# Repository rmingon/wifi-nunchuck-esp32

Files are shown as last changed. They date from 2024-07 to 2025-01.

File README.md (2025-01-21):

# Esp32 nunchuck

# video

Watch the video (https://youtu.be/Svnkp6KxDMc)

### Project for use a wii nunchuck on wifi or bluetooth

### 3d view
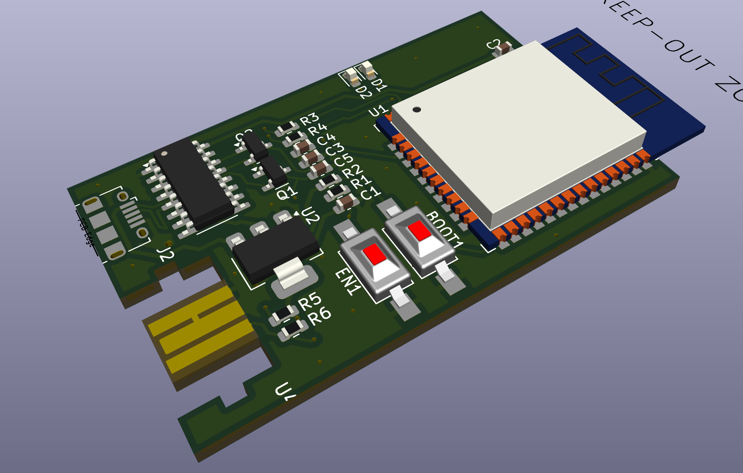
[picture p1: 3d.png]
wifi nunchuck 3d view


### Schematic view
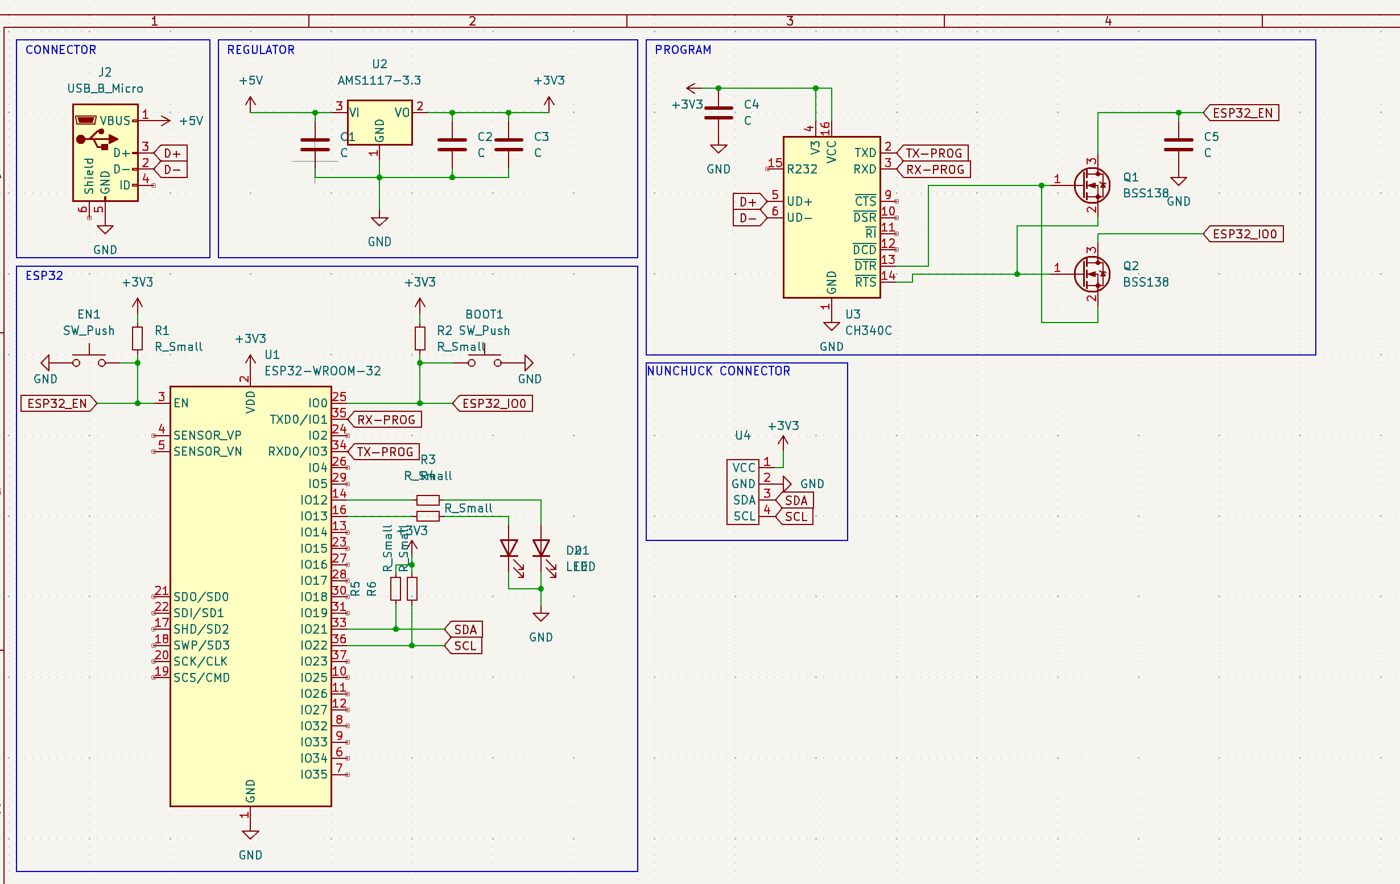
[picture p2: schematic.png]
wifi nunchuck schematic view


### Pcb view
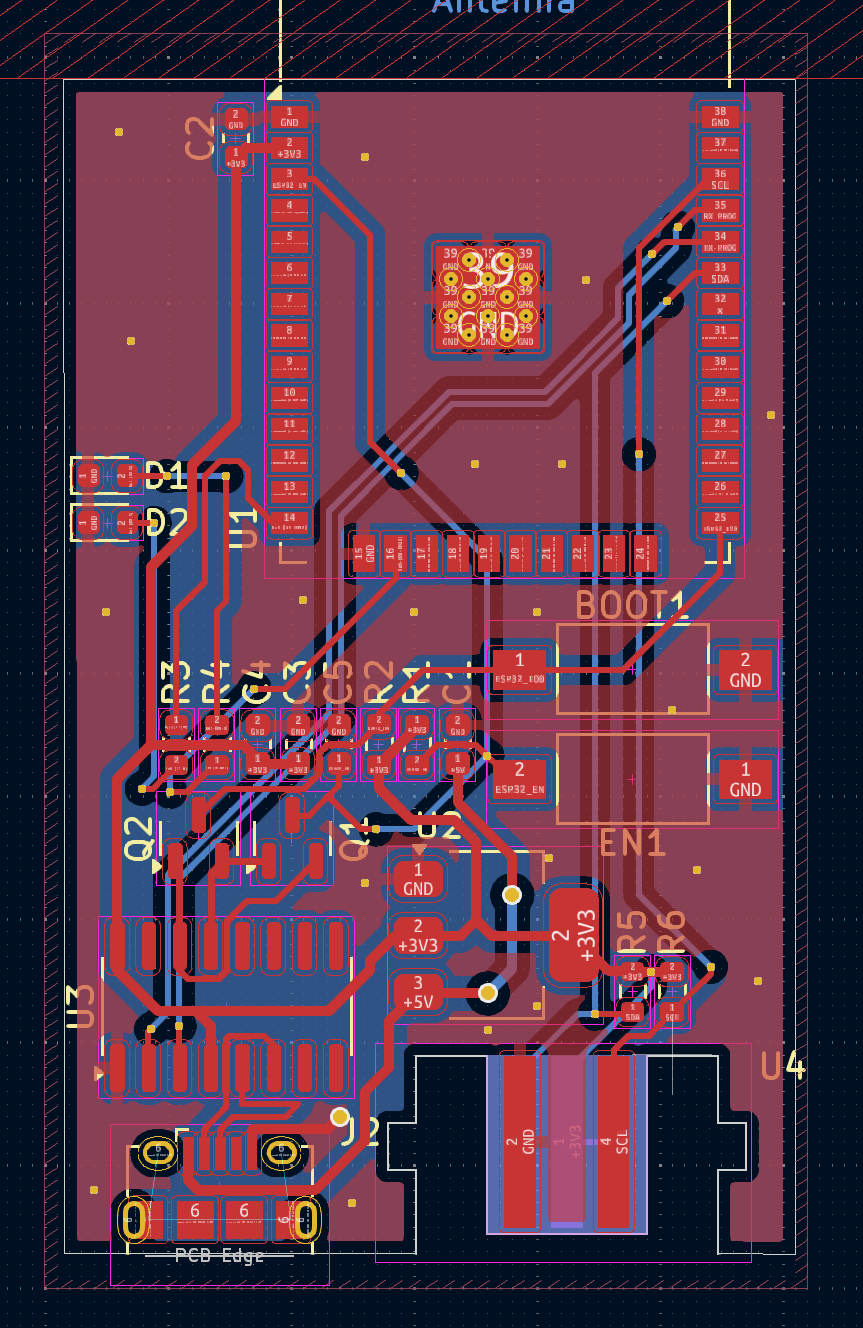
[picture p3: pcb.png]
wifi nunchuck pcb view


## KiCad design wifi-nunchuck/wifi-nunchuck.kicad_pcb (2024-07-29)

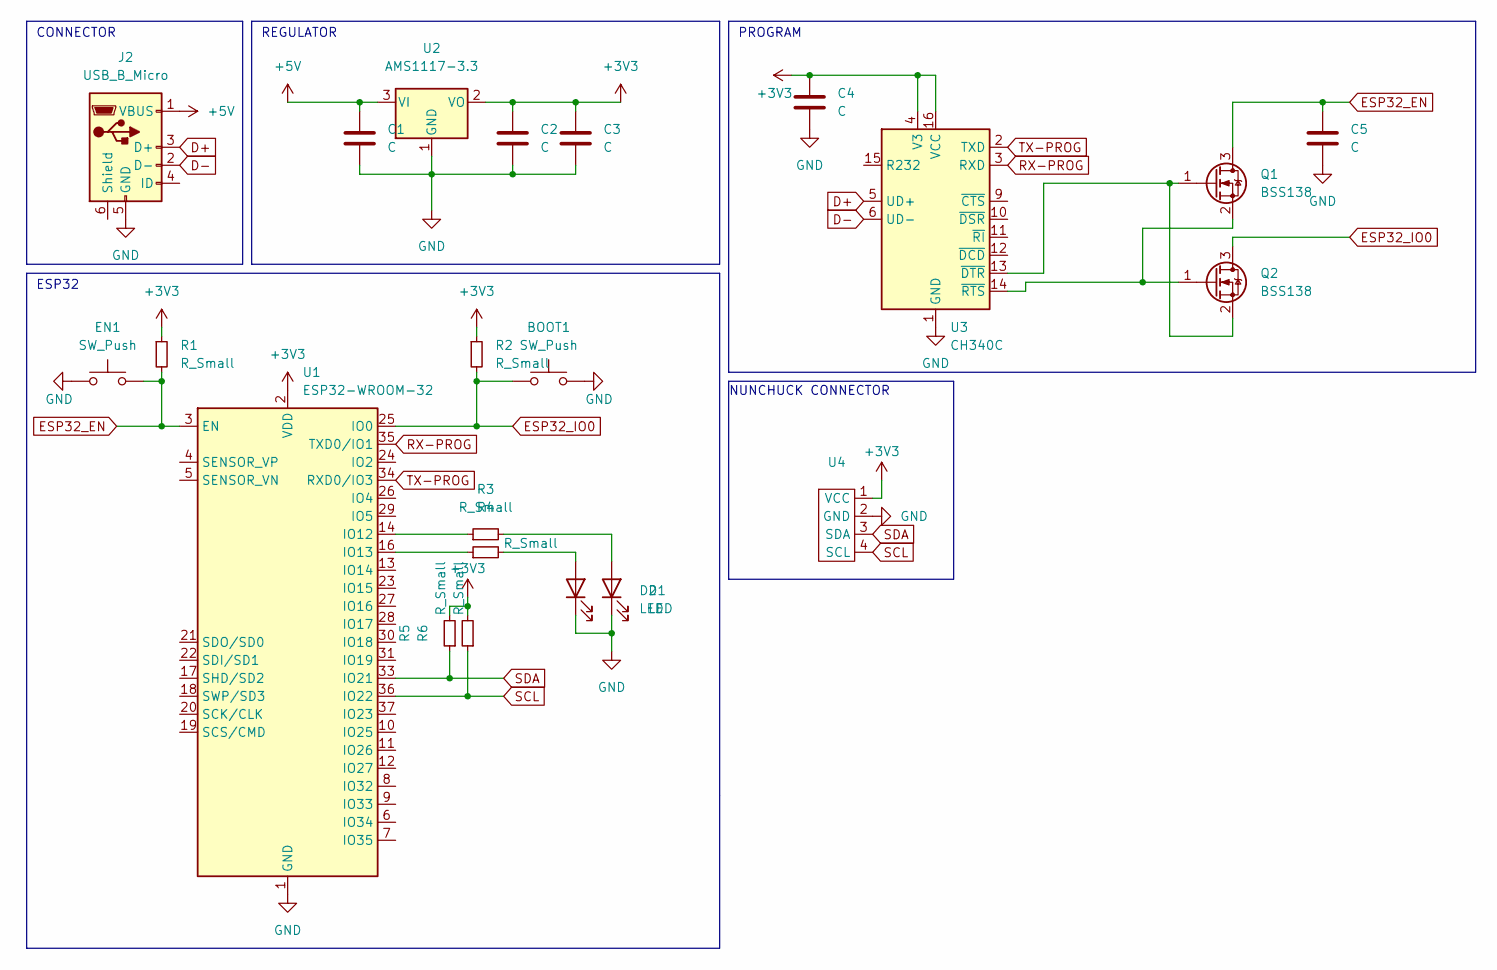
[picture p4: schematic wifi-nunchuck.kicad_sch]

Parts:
BOOT1: SW_Push; SW_SPST_FSMSM
C1, C2, C3, C4, C5: C; C_0603_1608Metric
D1, D2: LED; LED_0603_1608Metric
EN1: SW_Push; SW_SPST_FSMSM
J2: USB_B_Micro; USB_Micro-B_Amphenol_10118194_Horizontal
Q1, Q2: BSS138; SOT-23
R1, R2, R3, R4, R5, R6: R_Small; R_0603_1608Metric
U1: ESP32-WROOM-32
U2: AMS1117-3.3; SOT-223-3_TabPin2
U3: CH340C; SOIC-16_3.9x9.9mm_P1.27mm
U4: nunchuck

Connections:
+3V3: C2.1, C3.1, C4.1, R1.1, R2.1, R5.2, R6.2, U1.2 (VDD), U2.2 (VO), U3.4 (V3), U3.16 (VCC), U4.1 (VCC)
+5V: C1.1, J2.1 (VBUS), U2.3 (VI)
D+: J2.3 (D+), U3.5 (UD+)
D-: J2.2 (D-), U3.6 (UD-)
ESP32_EN: C5.1, EN1.2, Q1.3 (D), R1.2, U1.3 (EN)
ESP32_IO0: BOOT1.1, Q2.3 (D), R2.2, U1.25 (IO0)
GND: BOOT1.2, C1.2, C2.2, C3.2, C4.2, C5.2, D1.1 (K), D2.1 (K), EN1.1, J2.5 (GND), U1.1 (GND), U1.15 (GND), U1.38 (GND), U1.39 (GND), U2.1 (GND), U3.1 (GND), U4.2 (GND)
unnamed: D1.2 (A), R4.2
unnamed: D2.2 (A), R3.2
unnamed: Q1.1 (G), Q2.2 (S), U3.13 (~DTR)
unnamed: Q1.2 (S), Q2.1 (G), U3.14 (~RTS)
unnamed: R3.1, U1.14 (IO12)
unnamed: R4.1, U1.16 (IO13)
RX-PROG: U1.35 (TXD0/IO1), U3.3 (RXD)
SCL: R6.1, U1.36 (IO22), U4.4 (SCL)
SDA: R5.1, U1.33 (IO21), U4.3 (SDA)
TX-PROG: U1.34 (RXD0/IO3), U3.2 (TXD)

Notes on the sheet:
ESP32
NUNCHUCK CONNECTOR
REGULATOR
PROGRAM
CONNECTOR

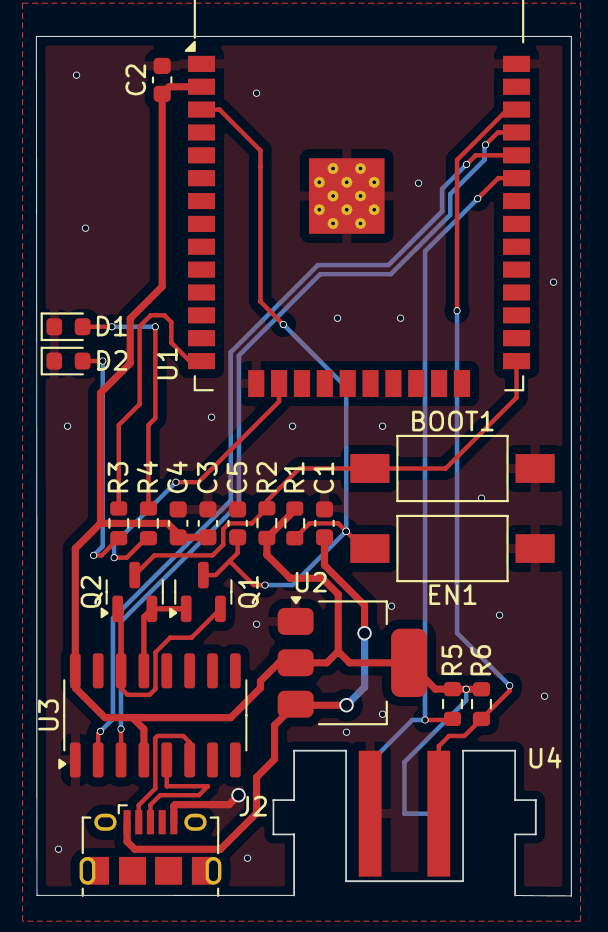
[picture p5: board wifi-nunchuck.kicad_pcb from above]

Board: 2 copper layers, 29.7 x 47.8 mm, 22 parts (0 on the bottom side), 17 nets.

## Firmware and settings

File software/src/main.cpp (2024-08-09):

#include <Arduino.h>
#include <WiFi.h>
#include <WiFiUdp.h>
WiFiUDP udp;

#include <WiiChuck.h>

#include "config.h"
#include <ArduinoJson.h>

char packetBuffer[2000];

int led = 12;

Accessory nunchuck;

bool buttonC, buttonZ = false;
int joyX, joyY, rollAngle, pitchAngle, accX, accY, accZ = 0;

String uniq = "";
void getMac() {
  byte mac[6];
  WiFi.macAddress(mac);
  uniq = String(mac[0],HEX) +String(mac[1],HEX) +String(mac[2],HEX) +String(mac[3],HEX) + String(mac[4],HEX) + String(mac[5],HEX);
}

void sendDataToServer(String type, JsonDocument data) {
  JsonDocument doc;
  doc["uniq"] = uniq;
  doc["type"] = type;
  doc["data"] = data;
  udp.beginPacket(SERVER_HOST_NAME, UDP_PORT);
  serializeJson(doc, udp);
  udp.endPacket();
}

void setup() {
  Serial.begin(115200);
  pinMode(led, OUTPUT);
  nunchuck.begin();
	if (nunchuck.type == Unknown) {
		nunchuck.type = NUNCHUCK;
	}
  getMac();

  WiFi.begin(SSID, PASSWORD);
  for(int i = 0; i < 10 && WiFi.status() != WL_CONNECTED; i++) {
      Serial.print(".");
      delay(1000);
  }

  udp.begin(UDP_PORT);
  JsonDocument data;
  sendDataToServer("controller", data);
  digitalWrite(led, HIGH);


  nunchuck.readData();
  joyX = nunchuck.values[0];
  joyY = nunchuck.values[1];
  rollAngle = nunchuck.values[2];
  pitchAngle = nunchuck.values[3];
  accX = nunchuck.values[4];
  accY = nunchuck.values[5];
  accZ = nunchuck.values[6];
}

void loop() {
  nunchuck.readData();
  JsonDocument motion;
  
  if(nunchuck.values[0] != joyX) {
    motion["joyX"] = nunchuck.values[0] - 127;
    joyX = nunchuck.values[0];
  }
  
  if(nunchuck.values[1] != joyY) {
    motion["joyY"] = nunchuck.values[1] - 127;
    joyY = nunchuck.values[1];
  }
  
  if(nunchuck.values[2] != rollAngle) {
    motion["rollAngle"] = nunchuck.values[2] - 127;
    rollAngle = nunchuck.values[2];
  }
  
  if(nunchuck.values[3] != pitchAngle) {
    motion["pitchAngle"] = nunchuck.values[3] - 127;
    pitchAngle = nunchuck.values[3];
  }

  if(nunchuck.values[4] != accX) {
    motion["accX"] = nunchuck.values[4] - 127;
    accX = nunchuck.values[4];
  }
  
  if(nunchuck.values[5] != accY) {
    motion["accY"] = nunchuck.values[5] - 127;
    accY = nunchuck.values[5];
  }
  
  if(nunchuck.values[6] != accZ) {
    motion["accZ"] = nunchuck.values[6] - 127;
    accZ = nunchuck.values[6];
  }

  if (nunchuck.values[10] > 20 != buttonZ) {
    motion["buttonZ"] = nunchuck.values[10] > 20 ? true : false;
    buttonZ = nunchuck.values[10] > 20 ? true : false;
  }
  if (nunchuck.values[11] > 20 != buttonC) {
    motion["buttonC"] = nunchuck.values[11] > 20 ? true : false;
    buttonC = nunchuck.values[11] > 20 ? true : false;
  }

  if (motion.size() > 0) {
    sendDataToServer("motion", motion);
  }

  Serial.print("JoyX = ");Serial.println(nunchuck.values[0]);//Joystick axe X
  Serial.print("JoyY = ");Serial.println(nunchuck.values[1]);//Joystick axe Y
  Serial.print("RollAngle = ");Serial.println(nunchuck.values[2]);//Angle de roulis
  Serial.print("PitchAngle = ");Serial.println(nunchuck.values[3]);//Angle d'inclinaison
  Serial.print("AccX = ");Serial.println(nunchuck.values[4]);//Acceleration axe X
  Serial.print("AccY = ");Serial.println(nunchuck.values[5]);//Acceleration axe Y
  Serial.print("AccZ = ");Serial.println(nunchuck.values[6]);//Acceleration axe Z
  Serial.print("BoutonZ = ");Serial.println(nunchuck.values[10] > 20 ? true : false);//Bouton Z
  Serial.print("BoutonC = ");Serial.println(nunchuck.values[11] > 20 ? true : false);//Bouton C
}

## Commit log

2024-07-26 pcb wiring
    [wifi-nunchuck.kicad_pcb]
2024-07-26 add gnd plane
    [wifi-nunchuck.kicad_pcb]
2024-07-26 update gnd
    [wifi-nunchuck.kicad_pcb]
2024-07-26 add views
    [wifi-nunchuck.kicad_sch]
2024-07-29 update plit settings
    [wifi-nunchuck.kicad_pcb]
2024-08-08 add led
